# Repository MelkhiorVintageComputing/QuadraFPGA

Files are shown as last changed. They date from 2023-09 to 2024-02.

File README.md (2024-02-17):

# A FPGA on a Quadra PDS card...

## Goal

The goal of this repository is to be able to interface a modern (2023 era) [FPGA](https://en.wikipedia.org/wiki/Field-programmable_gate_array) with a [Macintosh Quadra](https://en.wikipedia.org/wiki/Macintosh_Quadra) using its PDS (Processor Direct Slot) connector. The PDS is basically just a physical connector to the MC68040 memory bus.

So unless you're a retrocomputing enthusiast with such a machine, this is useless. If you are such an enthusiast, then maybe the ability to connect a modern LCD monitor using a digital interface to an old Macintosh might be of interest to you.

This project was 'spun off' the [NuBusFPGA](https://github.com/rdolbeau/NuBusFPGA) and [IIsiFPGA](https://github.com/rdolbeau/IIsiFPGA), similar project for the NuBus used in several models of Macintosh of the era and the PDS in the Macintosh IIsi. NuBusFPGA itself is a spin-off of the [SBusFPGA](https://github.com/rdolbeau/SBusFPGA), a similar project for the SBus used in Sun's SPARCstation.

## Current status

The HDMI (Highly Desirable Macintosh Interface) is working, with both video (single-hardware-res, multi-depth, windowboxed lower res) & audio working. More details are available in the readme of the NuBusFPGA repository.

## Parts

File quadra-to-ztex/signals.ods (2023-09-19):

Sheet: length
signal | pin (FPGA) | pin (board) | Ztex 2.13 | Current | Total | Missing | Should be | Prev
HDMI_D2+ | N2 | C27 | 15,81 | 33,028 | 48,838 | 0 | 33,028 | 64,105
HDMI_D2- | N1 | C28 | 16,75 | 32,088 | 48,838 | 0 | 32,088 | 57,775
HDMI_D1+ | L4 | D27 | 17,29 | 31,548 | 48,838 | 0 | 31,548 | 64,819
HDMI_D1- | K5 | D28 | 18,35 | 30,488 | 48,838 | 0 | 30,488 | 62,819
HDMI_D0+ | M1 | C30 | 20,19 | 28,648 | 48,838 | 0 | 28,648 | 55,571
HDMI_D0- | L1 | C29 | 18,52 | 30,318 | 48,838 | 0 | 30,318 | 50,731
HDMI_CLK+ | K3 | D30 | 22,14 | 26,698 | 48,838 | 0 | 26,698 | 50,299
HDMI_CLK- | L3 | D29 | 20,28 | 28,558 | 48,838 | 0 | 28,558 | 49,619
 |  |  |  |  | 48,838
PMOD-56- | P2 | D26 | 15,93 | 70,215 | 86,145 | 0 | 70,215
PMOD-56+ | R2 | D25 | 14,18 | 71,965 | 86,145 | 0 | 71,965
PMOD-78- | R1 | D24 | 12,91 | 73,235 | 86,145 | 0 | 73,235
PMOD-78+ | T1 | D23 | 11,52 | 74,625 | 86,145 | 0 | 74,625
PMOD-910- | P3 | D22 | 13,62 | 72,525 | 86,145 | 0 | 72,525
PMOD-910+ | P4 | D21 | 14,73 | 71,415 | 86,145 | 0 | 71,415
PMOD-1112- | N5 | D20 | 17,59 | 68,555 | 86,145 | 0 | 68,555
PMOD-1112+ | P5 | D19 | 19,51 | 66,635 | 86,145 | 0 | 66,635
 |  |  |  |  | 86,145

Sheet: 2.13 pin -> trace length
A3 | 47,94
A4 | 50,82
A5 | 49,92
A6 | 46,16
A7 | 41,01
A8 | 36,34
A9 | 35,18
A10 | 31,47
A11 | 29,79
A12 | 28,44
A13 | 25,47
A14 | 33,51
A18 | 19,12
A19 | 16,11
A20 | 12,52
A21 | 11,42
A22 | 16,17
A23 | 12,65
A24 | 16,68
A25 | 18,84
A26 | 14,67
A27 | 17,14
A28 | 22,76
A29 | 23,12
A30 | 26,67
B3 | 47,46
B4 | 43,6
B5 | 50,53
B6 | 43,56
B7 | 41,18
B8 | 38,13
B9 | 33,55
B10 | 30,82
B11 | 42,85
B12 | 26,76
B13 | 23,54
B14 | 21,66
B18 | 12,94
B19 | 10,5
B20 | 7,79
B21 | 4,99
B22 | 7,67
B23 | 6,56
B24 | 9,37
B25 | 11,32
B26 | 10,64
B27 | 14,66
B28 | 16,13
B29 | 18,45
B30 | 19,53
C3 | 48,06
C4 | 50,42
C5 | 44,03
C6 | 40,65
C7 | 40,55
C8 | 36,89
C9 | 42,83
C10 | 40,83
C11 | 29,53
C12 | 28,85
C13 | 23,26
C14 | 22,23
C15 | 29,19
C19 | 15,66
C20 | 13,54
C21 | 13,92
C22 | 10,82
C23 | 8,85
C24 | 10,26
C25 | 10,34
C26 | 10,91
C27 | 15,81
C28 | 16,75
C29 | 18,52
C30 | 20,19
D3 | 48,26
D4 | 47,25
D5 | 44,17
D6 | 47,7
D7 | 40,07
D8 | 43,24
D9 | 36,91
D10 | 36,12
D11 | 31,28
D12 | 28,32
D13 | 27,1
D14 | 24,45
D15 | 23,76
D19 | 19,51
D20 | 17,59
D21 | 14,73
D22 | 13,62
D23 | 11,52
D24 | 12,91
D25 | 14,18
D26 | 15,93
D27 | 17,29
D28 | 18,35
D29 | 20,28
D30 | 22,14

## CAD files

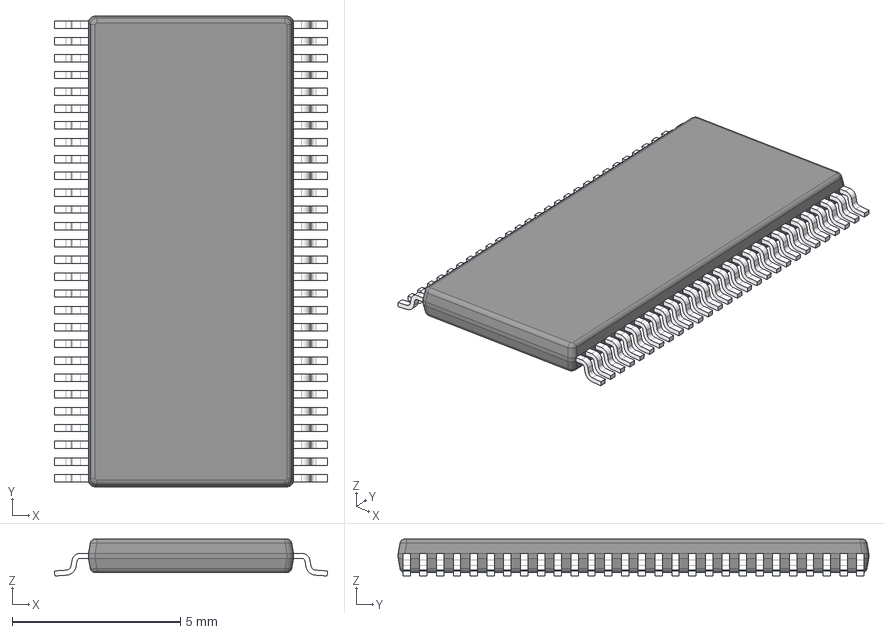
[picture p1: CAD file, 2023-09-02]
quadra-to-ztex/74CB3T16211DGGR.stp
8.12 x 14.0 x 1.10 mm
BODY-SO
LEAD-SO x 56
PIN1-ID

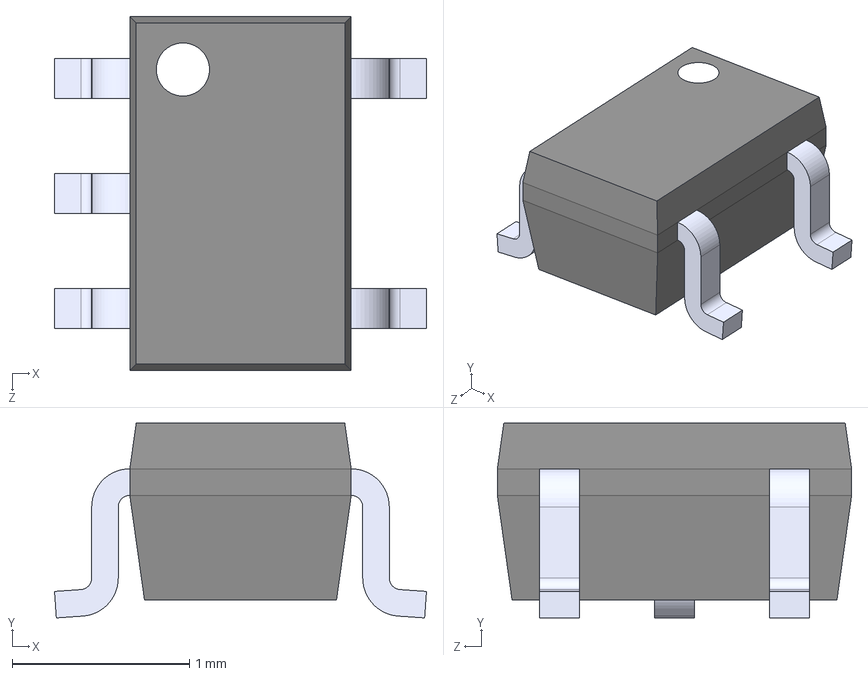
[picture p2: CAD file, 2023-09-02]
quadra-to-ztex/SN74LV1T125DCKR.step
2.10 x 1.10 x 2.00 mm

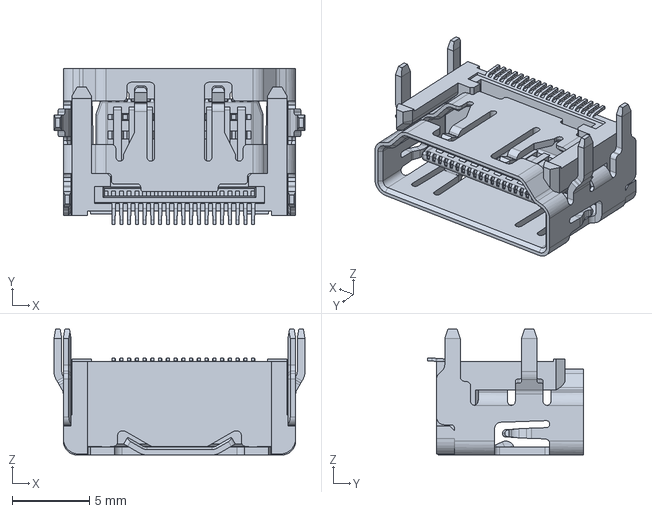
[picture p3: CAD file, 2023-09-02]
quadra-to-ztex/10029449-111RLF.stp
16.2 x 10.1 x 8.13 mm

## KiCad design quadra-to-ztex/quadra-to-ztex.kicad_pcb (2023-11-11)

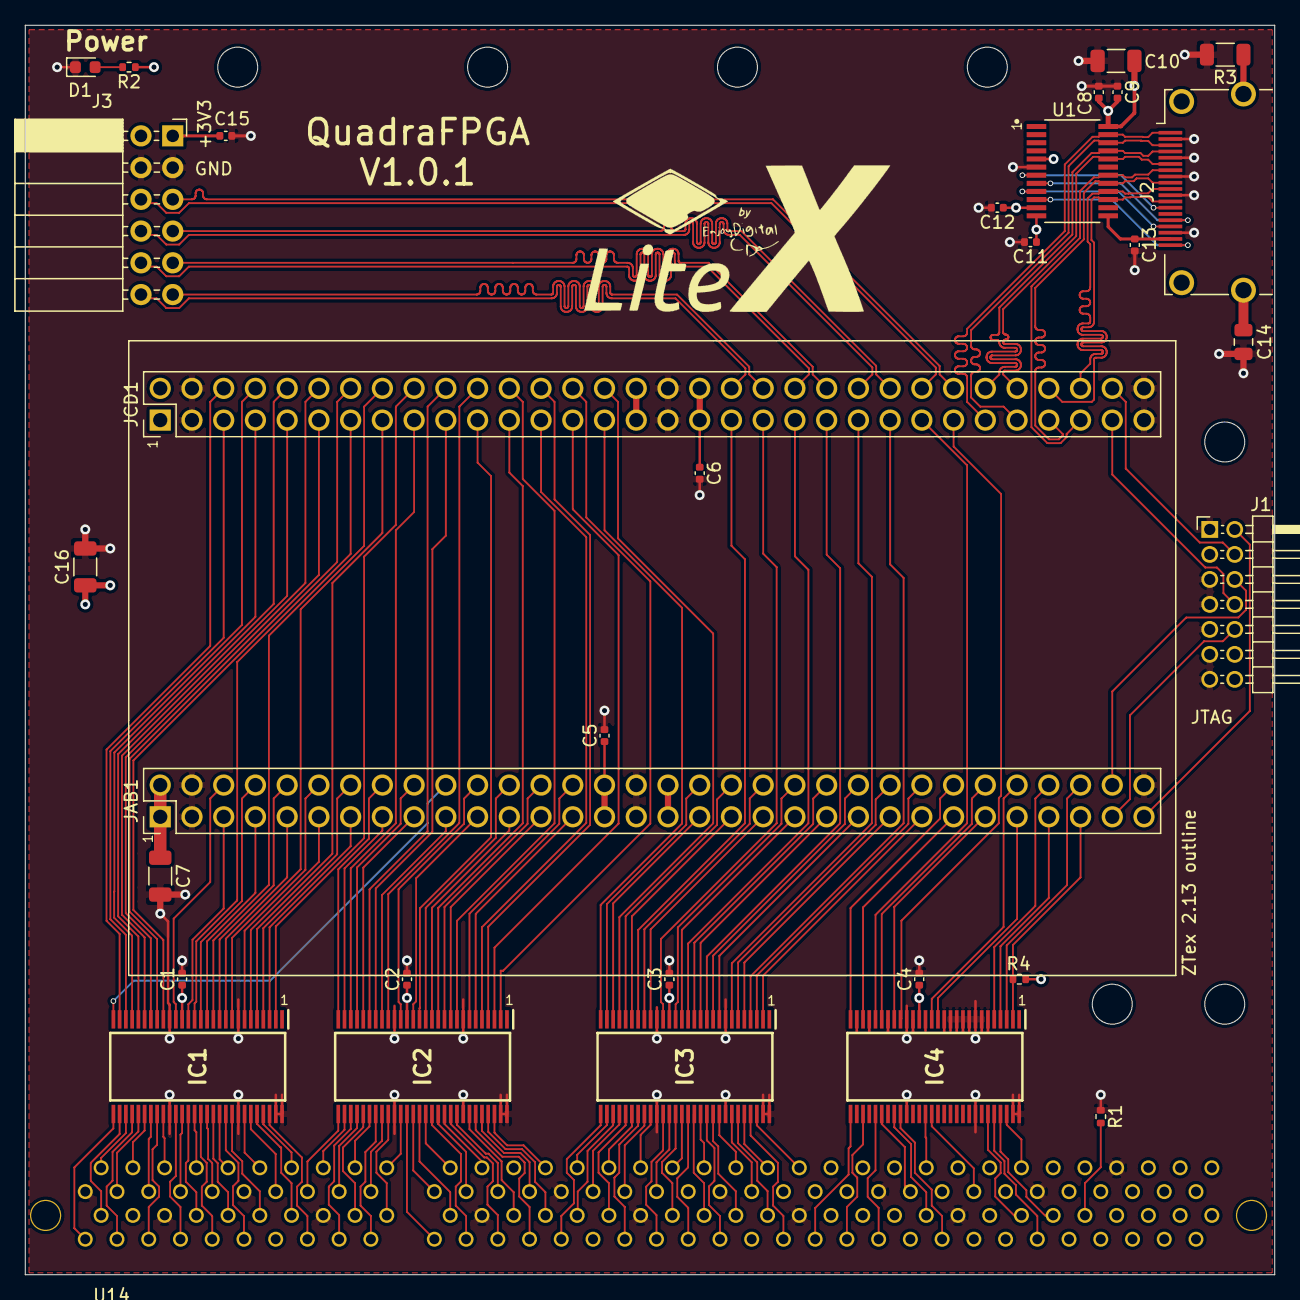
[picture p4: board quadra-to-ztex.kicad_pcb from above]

Board: 4 copper layers, 100.0 x 100.0 mm, 33 parts (0 on the bottom side), 200 nets.

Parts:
C1, C2, C3, C4, C5, C6, C8, C11, C12, C13, C15: 100nF; C_0402_1005Metric
C7, C16: 47uF 10V+; C_1206_3216Metric
C9: 10nF; C_0402_1005Metric
C10: 47uF 10V 1206; C_1206_3216Metric
C14: 10nF 1kV 0805; C_0805_2012Metric
D1: RED LED 0603; LED_0603_1608Metric
GRAPHIC1: LogoLitex; litex_logo
IC1, IC2, IC3, IC4: 74CB3T16211DGGR; SOP50P810X120-56N
J1: Conn_02x07_Odd_Even; PinHeader_2x07_P2.00mm_Horizontal_For_SeeedStudio
J2: 10029449-111RLF (HDMI A); HDMI_A_Amphenol_10029449-111
J3: A2541HWR-2x6P (Pmod 2x6 F R); PinSocket_2x06_P2.54mm_Horizontal
JAB1: ZTEX_AB-ztex_AB; PinHeader_2x32_P2.54mm_Vertical_For_SeeedStudio
JCD1: ZTEX_CD-ztex_CD; PinHeader_2x32_P2.54mm_Vertical_For_SeeedStudio
R1: 0; R_0402_1005Metric
R2: 680; R_0402_1005Metric
R3: 1M 500V 1206; R_1206_3216Metric
R4: 10k; R_0402_1005Metric
U1: TPD12S016PWR; SOP65P640X120-24N
U14: 8807-140-170LH

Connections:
+3V3: C1.1, C2.1, C3.1, C4.1, C5.1, C6.1, C8.1, C9.1, C10.1, C11.1, C15.1, C16.1, IC1.17, IC2.17, IC3.17, IC4.17, J3.1, J3.2, JAB1.29, JAB1.30, JAB1.33, JAB1.34, JCD1.31, JCD1.32, JCD1.35, JCD1.36, R2.1, R4.1, U1.5, U1.12, U1.24
+5V: C7.1, C12.1, JAB1.1, JAB1.2, U1.11, U14.26, U14.37, U14.56, U14.70, U14.74, U14.83, U14.101, U14.111, U14.121, U14.131, U14.140
/B2B/JTAG_VIO: J1.2, JAB1.63
/hdmi/HDMI_5V: C13.1, J2.18, U1.13
/hdmi/cec_b: J2.13, U1.7
/hdmi/hpd_b: J2.19, U1.10
/hdmi/scl_b: J2.15, U1.8
/hdmi/sda_b: J2.16, U1.9
A0: IC1.30, U14.72
A0_3V3: IC1.27, JCD1.6
A1: IC1.31, U14.2
A1_3V3: IC1.26, JCD1.5
A2: IC1.32, U14.73
A2_3V3: IC1.25, JCD1.8
A3: IC1.33, U14.3
A3_3V3: IC1.24, JCD1.7
A4: IC1.34, U14.4
A4_3V3: IC1.23, JCD1.10
A5: IC1.36, U14.75
A5_3V3: IC1.21, JCD1.12
A6: IC1.35, U14.5
A6_3V3: IC1.22, JCD1.9
A7: IC1.37, U14.6
A7_3V3: IC1.20, JCD1.11
A8: IC1.39, U14.77
A8_3V3: IC1.18, JAB1.6
A9: IC1.40, U14.7
A9_3V3: IC1.16, JAB1.5
A10: IC1.41, U14.78
A10_3V3: IC1.15, JCD1.14
A11: IC1.42, U14.8
A11_3V3: IC1.14, JAB1.8
A12: IC1.43, U14.79
A12_3V3: IC1.13, JAB1.7
A13: IC1.44, U14.9
A13_3V3: IC1.12, JCD1.13
A14: IC1.45, U14.80
A14_3V3: IC1.11, JAB1.10
A15: IC1.46, U14.10
A15_3V3: IC1.10, JAB1.9
A16: IC1.47, U14.81
A16_3V3: IC1.9, JCD1.16
A17: IC1.48, U14.82
A17_3V3: IC1.7, JAB1.12
A18: IC1.50, U14.12
A18_3V3: IC1.6, JAB1.11
A19: IC1.51, U14.13
A19_3V3: IC1.5, JCD1.15
A20: IC1.52, U14.84
A20_3V3: IC1.4, JAB1.14
A21: IC1.53, U14.14
A21_3V3: IC1.3, JAB1.13
A22: IC1.54, U14.85
A22_3V3: IC1.2, JCD1.18
A23: IC2.29, U14.15
A23_3V3: IC2.28, JAB1.16
A24: IC2.30, U14.16
A24_3V3: IC2.27, JAB1.15
A25: IC2.31, U14.87
A25_3V3: IC2.26, JCD1.17
A26: IC2.32, U14.17
A26_3V3: IC2.25, JAB1.18
A27: IC2.33, U14.88
A27_3V3: IC2.24, JAB1.17
A28: IC2.35, U14.89
A28_3V3: IC2.22, JCD1.19
A29: IC2.34, U14.18
A29_3V3: IC2.23, JCD1.20
A30: IC2.37, U14.90
A30_3V3: IC2.20, JCD1.22
A31: IC2.36, U14.19
A31_3V3: IC2.21, JAB1.19
AUX_CPUCLK: IC1.29, U14.71
AUX_CPUCLK_3V3: IC1.28, JAB1.20
D0: IC3.46, U14.109
D0_3V3: IC3.10, JAB1.46
D1: IC3.45, U14.38
D1_3V3: IC3.11, JCD1.43
D2: IC3.44, U14.108
D2_3V3: IC3.12, JAB1.43
D3: IC3.43, U14.107
D3_3V3: IC3.13, JAB1.44
D4: IC3.42, U14.36
D4_3V3: IC3.14, JCD1.41
D5: IC3.41, U14.106
D5_3V3: IC3.15, JAB1.41
D6: IC3.40, U14.35
D6_3V3: IC3.16, JAB1.42
D7: IC3.39, U14.105
D7_3V3: IC3.18, JCD1.39
D8: IC3.37, U14.34
D8_3V3: IC3.20, JAB1.39
D9: IC3.36, U14.33
D9_3V3: IC3.21, JAB1.40
D10: IC3.35, U14.103
D10_3V3: IC3.22, JCD1.37
D11: IC3.34, U14.32
D11_3V3: IC3.23, JAB1.37
D12: IC3.33, U14.102
D12_3V3: IC3.24, JAB1.38
D13: IC3.32, U14.31
D13_3V3: IC3.25, JCD1.30
D14: IC3.30, U14.30
D14_3V3: IC3.27, JAB1.36
D15: IC3.31, U14.100
D15_3V3: IC3.26, JAB1.35
D16: IC3.29, U14.99
D16_3V3: IC3.28, JCD1.29
D17: IC2.54, U14.28
D17_3V3: IC2.2, JCD1.28
D18: IC2.53, U14.98
D18_3V3: IC2.3, JCD1.27
D19: IC2.52, U14.27
D19_3V3: IC2.4, JCD1.26
D20: IC2.51, U14.97
D20_3V3: IC2.5, JCD1.25
D21: IC2.50, U14.96
D21_3V3: IC2.6, JAB1.27
D22: IC2.48, U14.25
D22_3V3: IC2.7, JAB1.28
D23: IC2.47, U14.95
D23_3V3: IC2.9, JCD1.24
D24: IC2.46, U14.24
D24_3V3: IC2.10, JAB1.25
D25: IC2.45, U14.23
D25_3V3: IC2.11, JAB1.26
D26: IC2.44, U14.93
D26_3V3: IC2.12, JCD1.23
D27: IC2.43, U14.22
D27_3V3: IC2.13, JAB1.23
D28: IC2.42, U14.92
D28_3V3: IC2.14, JAB1.24
D29: IC2.41, U14.21
D29_3V3: IC2.15, JCD1.21
D30: IC2.40, U14.91
D30_3V3: IC2.16, JAB1.21
D31: IC2.39, U14.20
D31_3V3: IC2.18, JAB1.22
FPGA_JTAG_TCK: J1.6, JAB1.62
FPGA_JTAG_TDI: J1.10, JAB1.61
FPGA_JTAG_TDO: J1.8, JCD1.61
FPGA_JTAG_TMS: J1.4, JCD1.62
GND: C1.2, C2.2, C3.2, C4.2, C5.2, C6.2, C7.2, C8.2, C9.2, C10.2, C11.2, C12.2, C13.2, C14.2, C15.2, C16.2, D1.1, IC1.8, IC1.19, IC1.38, IC1.49, IC1.55, IC1.56, IC2.8, IC2.19, IC2.38, IC2.49, IC2.55, IC2.56, IC3.8, IC3.19, IC3.38, IC3.49, IC3.55, IC3.56, IC4.6, IC4.7, IC4.8, IC4.9, IC4.10, IC4.11, IC4.12, IC4.13, IC4.16, IC4.18, IC4.19, IC4.22, IC4.25, IC4.27, IC4.38, IC4.49, IC4.55, IC4.56, J1.1, J1.3, J1.5, J1.7, J1.9, J1.11, J1.13, J2.2, J2.5, J2.8, J2.11, J2.17, J3.3, J3.4, JAB1.3, JAB1.4, JAB1.31, JAB1.32, JAB1.64, JCD1.3, JCD1.4, JCD1.33, JCD1.34, JCD1.63, JCD1.64, R1.1, R3.2, U1.6, U14.1, U14.11, U14.29, U14.39, U14.49, U14.59, U14.64, U14.76, U14.86, U14.94, U14.104, U14.114, U14.124
HDMI_CLK+: J2.10, JCD1.60, U1.16
HDMI_CLK-: J2.12, JCD1.58, U1.15
HDMI_D0+: J2.7, JCD1.59, U1.18
HDMI_D0-: J2.9, JCD1.57, U1.17
HDMI_D1+: J2.4, JCD1.54, U1.21
HDMI_D1-: J2.6, JCD1.56, U1.20
HDMI_D2+: J2.1, JCD1.53, U1.23
HDMI_D2-: J2.3, JCD1.55, U1.22
unnamed: D1.2, R2.2
PMOD-56+: J3.6, JCD1.50
PMOD-56-: J3.5, JCD1.52
PMOD-78+: J3.8, JCD1.46
PMOD-78-: J3.7, JCD1.48
PMOD-910+: J3.10, JCD1.42
PMOD-910-: J3.9, JCD1.44
PMOD-1112+: J3.12, JCD1.38
PMOD-1112-: J3.11, JCD1.40
SHIELD: C14.1, J2.SH, R3.1
SIZ0: IC3.47, U14.110
SIZ0_3V3: IC3.9, JAB1.45
SIZ1: IC3.48, U14.40
SIZ1_3V3: IC3.7, JCD1.45
TM0: IC4.51, U14.128
TM0_3V3: IC4.5, JAB1.58
TM1: IC4.52, U14.129
TM1_3V3: IC4.4, JAB1.57
TM2: IC4.53, U14.130
TM2_3V3: IC4.3, JAB1.60
TT0: IC4.36, U14.122
TT0_3V3: IC4.21, JAB1.53
TT1: IC4.37, U14.123
TT1_3V3: IC4.20, JCD1.51
~BB: IC4.41, U14.52
~BB_3V3: IC4.15, JAB1.56
~BG_40SLOT: IC4.33, U14.119
~BG_40SLOT_3V3: IC4.24, JCD1.49
~BR_40SLOT: IC4.34, U14.51
~BR_40SLOT_3V3: IC4.23, JAB1.54
~MI: IC4.31, U14.117
~MI_3V3: IC4.26, JAB1.51
~NMRQ6: IC4.54, U14.58
~NMRQ6_3V3: IC4.2, JAB1.59, R4.2
~PDS_SLOT_E_EN: R1.2, U14.132
~RSTQ: IC4.42, U14.55
~RSTQ_3V3: IC4.14, JAB1.55
~RW: IC3.50, U14.41
~RW_3V3: IC3.6, JAB1.48
~TA: IC3.53, U14.113
~TA_3V3: IC3.3, JAB1.50
~TBI: IC3.51, U14.112
~TBI_3V3: IC3.5, JAB1.47
~TEA: IC3.54, U14.44
~TEA_3V3: IC3.2, JAB1.49
~TIP_CPU: IC3.52, U14.42
~TIP_CPU_3V3: IC3.4, JCD1.47
~TS: IC4.29, U14.115
~TS_3V3: IC4.28, JAB1.52

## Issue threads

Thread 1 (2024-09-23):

Doesn't work at 40mhz in Q650

ZigZagJoe, 2024-09-23:
Hey! Fantastic piece of work. I got one of these off jockelill at VCFMW to play with.

Just as a heads up, it doesn't work at 40mhz in a Quadra 650 (wombat) board. Seems that it will partially read some DeclROM structures into slot manager structures, then the card stops replying and will give bus errors when I try look for its declrom anywhere in $FEFF0000. Most often it just won't show in slot manager at all.

However, possibly the Macsbug looking for ROM methodology may not be a good one, as it seems like the card also goes unresponsive and will bus error at fbIrq trying to read from the card after exiting MacsBug (while at 33mhz).

Replication:

1. Install a jumper/switch at J29 (recommended) to allow swapping between the crystal at G3 (x2) and 40mhz bus speed. Or install a 20mhz crystal at G3
2. Install QuadraFPGA, boot machine
3. No display output; typically not listed in tattletech but sometimes will be seen with partially populated sResources and no board info.

No real need for this to be fixed, more of a FYI, but figured it'd be good to get it written down somewhere :)

rdolbeau, 2024-09-23:
40 MHz might be a bit much for the current design. In theory there's no reason why it shouldn't work (40MHz is not a lot for an Artix-7 FPGA), but in practice the lack of proper timing specifications (I still can't figure that stuff out and it mostly work without...) and the low voltage used (the FPGA + CB3T combo only drive the bus to 3.3V, not 5V, though they can in practice reach more than the 2.4V required by 5V TTL) means sometimes the signals don't move quick enough... and then things break. But for now it's fairly 'deterministic': a given device in a given system will work, or it won't.

The IIsiFPGA is known to become extremely touchy (late /STERM causing double-write, maybe more) when combined on a riser with a '882 FPU and a IIsiSEthernet. I wouldn't be surprised if the QuadraFPGA was already borderline at 33 MHz, despite the design passing timings at 40 MHz on the CPU clock. Faster slew/higher drive would help, but then that can cause ringing which isn't great either...

Does it work for you under 'normal' operating condition at 33 MHz? That's the only thing that was tested... As for MacsBug, if you're poking and peeking at the device, it can be quite fragile as there's no protection against access to internally unmapped addresses. Reading from the ROM should be fine. Accessing unmapped addresses (or trying to write to read-only addresses) can cause internal issues that can only be resolved by a full device reset (i.e., rebooting the Mac).

ZigZagJoe, 2024-09-23:
I only just got it working last night after finding that 33mhz was required, so I haven't delved in any depth as of yet. Seems fine, though.

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

Interestingly, it's simply entering macsbug (@33mhz) that will cause it to bus erroring in the IRQ after exiting macsbug. This is with the FPGA set as a second display, as MacsBug has issues drawing on the FPGA screen as primary.

Timing being tight seems plausible since it's clearly reading *part* of the declrom before the card stops responding @ 40mhz, though it's interesting that it manages to read any of it at all, as you said, usually it's a bit of an all or nothing affair. (when it reads the ROM) the amount it gets before the card stops responding is inconsistent.

Just observations, anyways :) It is good to see this in action as the Pickles source, SuperMario and NubusFPGA were major touchpoints for me as I was writing my DeclROM for 30video.

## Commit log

2023-09-02 early draft
    [10029449-111RLF.stp, 74CB3T16211DGGR.stp, B2B.sch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]
2023-09-09 length tuning
    [PDS040.sch, quadra-to-ztex.kicad_pcb, signals.ods]
2023-09-16 remove memreset, add busmastering (?)
    [B2B.sch, PDS040.sch, quadra-to-ztex.kicad_pcb]
2023-09-17 upd gen files
    [B2B.sch, quadra-to-ztex.csv, quadra-to-ztex.kicad_pcb]
2023-09-17 rewire to avoid p/n conflicts
    [B2B.sch, quadra-to-ztex.kicad_pcb, signals.ods]
2023-09-19 fix lengths
    [quadra-to-ztex.kicad_pcb, signals.ods]
2023-09-23 oups A5
    [PDS040.sch, quadra-to-ztex.kicad_pcb]
2023-10-02 oups wrong pin
    [PDS040.sch]
2023-10-21 R1 must be 0 ohm (there's a pull-up on the motherboard and it's stronger)
    [PDS040.sch, quadra-to-ztex.kicad_pcb]
2023-11-11 fix A18 <-> A19 (hardware)
    [B2B.sch, PDS040.sch, quadra-to-ztex.kicad_pcb]
2023-11-18 move some of board platform stuff to common
2024-05-18 board-based name
2025-09-07 no DMA :-(
